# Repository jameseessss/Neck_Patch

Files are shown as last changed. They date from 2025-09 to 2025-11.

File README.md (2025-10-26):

# Neck Posture Rehab Patch
A lightweight, discreet neck-posture coach built on **nRF5340 + IMU**, providing real-time pitch/dwell estimation with **LRA haptics** and an optional **Peltier thermal cue**. The device connects over **BLE** for status streaming and parameter tuning.

> **What**: A wearable that senses head-neck posture and gently nudges you back to neutral.  
> **Why**: Prolonged forward-head posture is common with laptops/phones; this patch offers an adaptive, comfortable alternative to rigid braces.

---

## 📷 Bench & Design Gallery

<p align="center">
  Bench test of driver/LRA & Peltier control
</p>
<p align="center"><em>Figure 1 — Driver bench test (H-bridge + PWM + thermistor ADC). Used for LRA and Peltier bring-up.</em></p>

<p align="center">
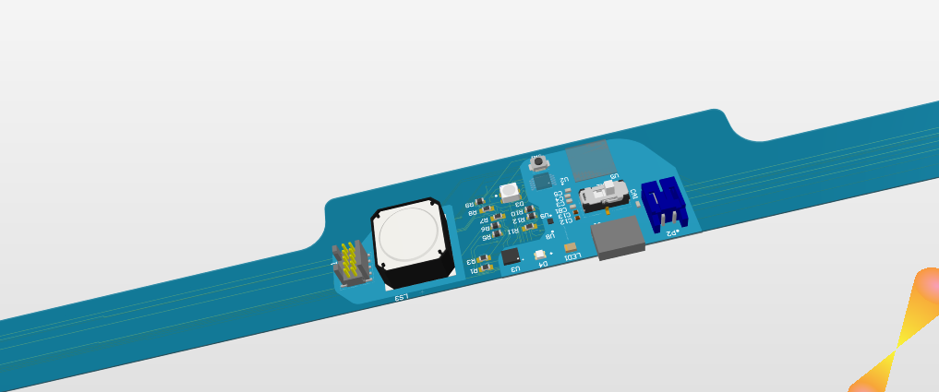
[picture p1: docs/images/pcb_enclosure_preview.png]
Preliminary flex PCB appearance / enclosure concept
  
</p>
<p align="center"><em>Figure 2 — Preliminary appearance concept for the flex PCB / enclosure.</em></p>

<p align="center">
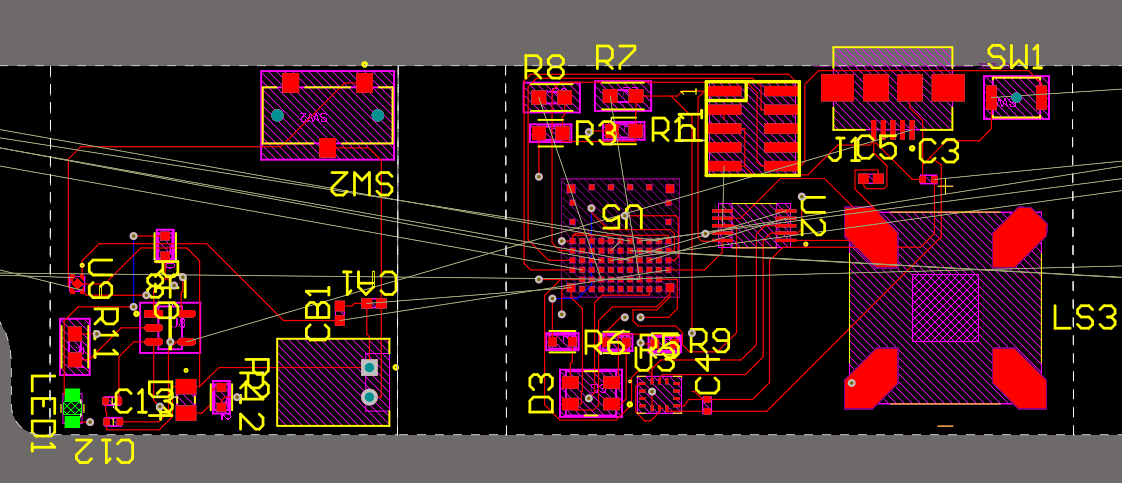
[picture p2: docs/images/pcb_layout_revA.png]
PCB Layout Rev-A (key nets and placement)
  
</p>
<p align="center"><em>Figure 3 — PCB Layout Rev-A snapshot: IMU, H-bridge, thermistor front-end, battery path.</em></p>

---

## ✨ Key Features
- **Real-time posture estimation**: 6-DoF IMU with *Madgwick* fusion for head-pitch tracking and **dwell time** measurement.
- **Fewer false triggers**: **Dynamic baseline** (adapts to user’s neutral drift) + **hysteresis thresholds** to avoid chatter.
- **Multi-modal feedback**:
  - **LRA haptics** with multiple intensity levels.
  - **Peltier thermal cue**: subtle skin-level warmth as a secondary, less intrusive signal.
- **BLE connectivity**: Custom **GATT** service for state notifications and command/control.
- **Safety & reliability**: Temperature/current limits, watchdog, emergency stop, error logging; OTA-ready (optional).
- **Early result**: Initial pilot suggests improved correction adherence over one week (larger study planned).

---

## 🧩 System Overview
- **MCU/SoC**: Nordic **nRF5340** (Zephyr RTOS) *(ESP32-S3 prototype supported)*  
- **Sensors**: BMI270 or ISM330DHCX (6-DoF IMU)  
- **Actuators**: LRA + driver; **Peltier + NTC** thermistor (optional)  
- **Connectivity**: BLE  
- **Power**: Single-cell Li-ion with charge/protection circuitry

### Thermal Subsystem (Peltier)
- **Purpose**: Provide a *gentle, low-salience* cue (warmth) when poor posture persists beyond a dwell threshold.
- **Control**: PWM-driven H-bridge → Peltier; closed-loop temperature control via **NTC** (skin-surface proxy).  
- **Algorithms**: NTC linearization, **slew-rate limiting**, and anti-windup.  
- **Safety limits (typical)**:
  - Skin-surface temperature cap (e.g., **≤ 42 °C** configurable)
  - Current limit with fold-back
  - Auto cool-down on over-temp / fault
- **Current HW rev**: Heating-focused; active cooling direction is possible with the H-bridge but disabled by default.

> ⚠️ **Note**: Thermal feedback targets *noticeable but comfortable* warmth. Actual limits should be validated per regulatory and dermatological guidance for wearables.

---

## 🔎 Current Status
- ✅ IMU fusion, posture logic, multi-level vibration  
- ✅ Peltier closed-loop heating with temp cap & current limit (pilot)

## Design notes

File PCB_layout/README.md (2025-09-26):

# ECE8873_Altium_sample

## Installing Altium
We have some specific instructions for installing, thanks to you classmate. Please see [these instructions](https://github.gatech.edu/ECE8873-Sensory-Sub-Aug/.github-private/blob/160f999e37ecde97cc4052183547c56a92e3dedc/profile/ALTIUM-Student%20License%20Request.pdf).

## Downloading sample
This is a git repository that you can clone like any other. It does not use the Altium workspace VCS. 
1. Fork this repository into the class organization
1. Use git command line tools to clone your fork on your desktop
1. In Altium, open the project (if it tells you the local copy is popinting to a VCS repository that is different from the one defined in the repository folder, PRESS CANCEL. Do not choose to get the repository from the ECE8873_sample or make the project local)
1. You can use the "Save to server" function in the project navigator to commit and push to your repository

## Working with Altium
- The main thing to start with in Altium is the schematic file and the board file (access these in the project navigation sidebar on left). In your project, you will most likely be adding additional sensors to your schematic, and then routing the board.
- Check for errors in the schematic (red zigzag lines)
- When you make changes to the schematic, go to the board file and click Design > Import changes from ...
- In the board file, you will see the footprints for the components arranged randomly. You will need to place them (move and rotate).
- There will be thin yellow lines telling you where connections need to be made. You need to route wires between each of these points (Ctrl + w). 
- The red traces are the top traces on the board, and the blue is the bottom traces. You can tunnel through the board with vias. While routing in interactive mode (Ctrl + w), switching between layers (Ctrl + Shift + scoll wheel) will automatically create a via.
- This sample contains good [design rules for PCBway](https://www.pcbway.com/capabilities.html). This is similar to the Altium .RUL file that they give [here](https://www.pcbway.com/helpcenter/design_instruction/PCBWay_Custom_Design_Rules.html), but I made some modifications.
- Check that your design passes clicking tools > Design rule check.

## Exporting for manufacturing by PCBway
- You will need to export both the gerber files and the drill files. See the guide [here](https://www.pcbway.com/blog/help_center/How_to_Generate_Gerber_and_Drill_Files_in_Altium_Designer_23_5_1_c436e1cc.html).
- The project includes samples of both the gerber and drill files.
- Make sure you look through each of the layers generated. Make sure your drills and soldermask layers show up in the right place.

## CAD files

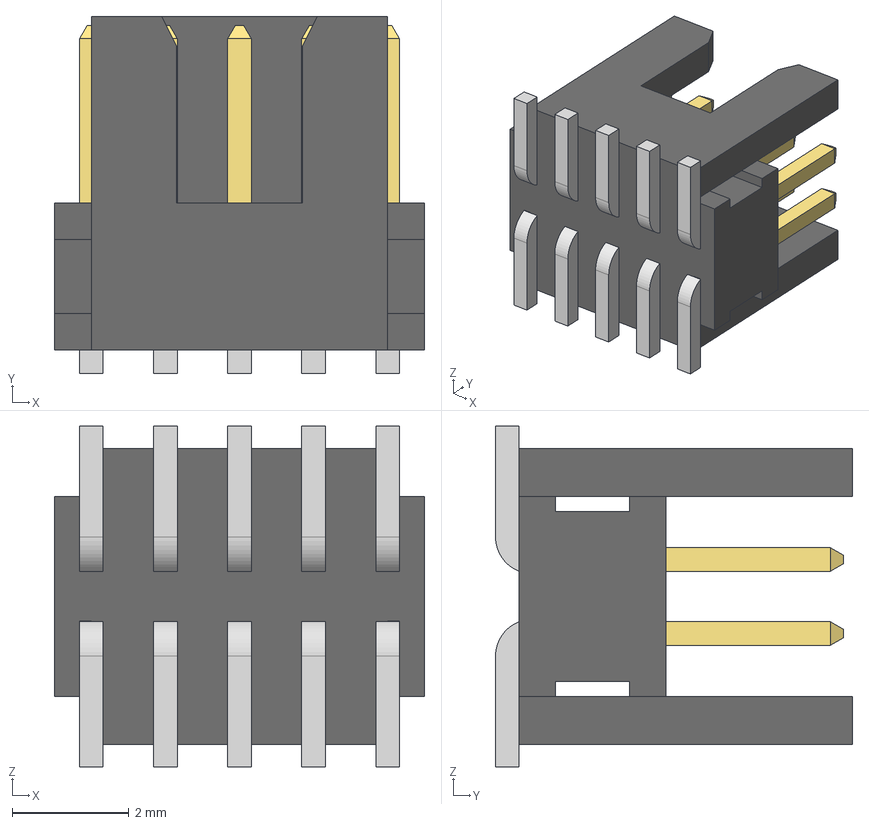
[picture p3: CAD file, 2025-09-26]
PCB_layout/Cad Files/FTSH-105-01-LM-DV-K-TR.stp
6.35 x 6.12 x 5.84 mm
FTSH-105-01-LM-DV-K-TR_body
FTSH-105-01-LM-DV-K-TR_pins1
FTSH-105-01-LM-DV-K-TR_pins2

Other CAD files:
PCB_layout/Cad Files/Temp Board Shape.SLDPRT
PCB_layout/Cad Files/RealFlex.SLDPRT
PCB_layout/Cad Files/RealFlex.DXF
PCB_layout/Cad Files/Temp Board Shape.DXF

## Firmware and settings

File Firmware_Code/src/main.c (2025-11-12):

/*
 * Copyright (c) 2021 Bosch Sensortec GmbH
 *
 * SPDX-License-Identifier: Apache-2.0
 */

#include <zephyr/kernel.h>
#include <zephyr/device.h>
#include <zephyr/devicetree.h>
#include <zephyr/drivers/sensor.h>
#include <zephyr/drivers/gpio.h>
#include <zephyr/drivers/adc.h>
#include <zephyr/drivers/pwm.h>
#include <zephyr/logging/log.h>
#include <math.h>
#include <stdio.h>
#include <stdint.h>
#include <errno.h>

LOG_MODULE_REGISTER(imu_test, LOG_LEVEL_INF);

/* ===== Thermistor Configuration ===== */
#define VREF_MV       3000.0
#define R_FIXED_OHM   10000.0
#define R0_OHM        10000.0
#define BETA          3950.0
#define T0_K          298.15
#define TEMP_CUTOFF   45.0

/* ===== PWM Peltier Configuration ===== */
#define PWM_PERIOD_NS   PWM_MSEC(10)   /* 10ms period */
#define PELTIER_OFF_NS  0
#define PELTIER_ON_NS   5000000        /* 50% duty cycle */

/* ===== LRA Vibration Motor Configuration ===== */
#define LRA_OFF_NS      0
#define LRA_ON_NS       5000000        /* 50% duty cycle */

/* ===== Global Variables ===== */
static int16_t adc_buf;
static struct adc_sequence adc_seq = {
    .buffer = &adc_buf,
    .buffer_size = sizeof(adc_buf),
};
static const struct adc_dt_spec adc_channel = ADC_DT_SPEC_GET(DT_PATH(zephyr_user));

/* ===== Function Declarations ===== */
static int read_thermistor_mv(int *out_mv);
static double thermistor_temp_c_from_mv(int vout_mv);
static int set_peltier_pwm(uint32_t pulse_ns);
static int set_lra_pwm(uint32_t pulse_ns);

/* ===== Thermistor Reading Function ===== */
static int read_thermistor_mv(int *out_mv)
{
    int err = adc_read(adc_channel.dev, &adc_seq);
    if (err < 0) {
        LOG_ERR("adc_read failed (%d)", err);
        return err;
    }
    int mv = (int)adc_buf;
    err = adc_raw_to_millivolts_dt(&adc_channel, &mv);
    if (err < 0) {
        LOG_WRN("adc_raw_to_millivolts not supported; raw=%d", (int)adc_buf);
        return -ENOTSUP;
    }
    *out_mv = mv;
    return 0;
}

/* ===== Temperature Calculation Function ===== */
static double thermistor_temp_c_from_mv(int vout_mv)
{
    if (vout_mv <= 1) vout_mv = 1;
    if (vout_mv >= (int)VREF_MV - 1) vout_mv = (int)VREF_MV - 1;

    double v = (double)vout_mv;
    double r_therm = R_FIXED_OHM * v / (VREF_MV - v); 
    double inv_T = (1.0 / T0_K) + (1.0 / BETA) * log(r_therm / R0_OHM);
    double T_k = 1.0 / inv_T;
    return T_k - 273.15;
}

/* ===== PWM Control Function ===== */
static int set_peltier_pwm(uint32_t pulse_ns)
{
    /* First Peltier: Use pwm_led0 alias */
    const struct pwm_dt_spec pwm_peltier1 = PWM_DT_SPEC_GET(DT_ALIAS(pwm_led0));
    /* Second Peltier: Use pwm_led2 alias (P1.12) */
    const struct pwm_dt_spec pwm_peltier2 = PWM_DT_SPEC_GET(DT_ALIAS(pwm_led2));
    
    int err1 = pwm_set_dt(&pwm_peltier1, PWM_PERIOD_NS, pulse_ns);
    int err2 = pwm_set_dt(&pwm_peltier2, PWM_PERIOD_NS, pulse_ns);
    
    if (err1 < 0) {
        LOG_ERR("Peltier1 PWM set failed (%d)", err1);
        return err1;
    }
    if (err2 < 0) {
        LOG_ERR("Peltier2 PWM set failed (%d)", err2);
        return err2;
    }
    
    return 0;
}

/* ===== LRA Vibration Motor Control Function ===== */
static int set_lra_pwm(uint32_t pulse_ns)
{
    const struct pwm_dt_spec pwm_lra1 = PWM_DT_SPEC_GET(DT_NODELABEL(lra_vib1));
    const struct pwm_dt_spec pwm_lra2 = PWM_DT_SPEC_GET(DT_NODELABEL(lra_vib2));
    
    int err1 = pwm_set_dt(&pwm_lra1, PWM_PERIOD_NS, pulse_ns);
    int err2 = pwm_set_dt(&pwm_lra2, PWM_PERIOD_NS, pulse_ns);
    
    if (err1 < 0) {
        LOG_ERR("LRA1 PWM set failed (%d)", err1);
        return err1;
    }
    if (err2 < 0) {
        LOG_ERR("LRA2 PWM set failed (%d)", err2);
        return err2;
    }
    
    return 0;
}

int main(void)
{
        const struct device *const dev = DEVICE_DT_GET_ONE(bosch_bmi270);
        struct sensor_value acc[3], gyr[3];
        struct sensor_value full_scale, sampling_freq, oversampling;
        
        /* LED GPIO device and pins */
        const struct device *gpio_dev = DEVICE_DT_GET(DT_NODELABEL(gpio0));
        
        /* Check if GPIO device is ready */
        if (!device_is_ready(gpio_dev)) {
                LOG_ERR("GPIO device not ready");
                return 0;
        }
        
        /* Configure LED pins as outputs */
        gpio_pin_configure(gpio_dev, 22, GPIO_OUTPUT_ACTIVE | GPIO_ACTIVE_HIGH);
        gpio_pin_configure(gpio_dev, 23, GPIO_OUTPUT_ACTIVE | GPIO_ACTIVE_HIGH);
        
        LOG_INF("LEDs configured on P0.22 and P0.23");
        
        /* Initialize ADC for thermistor (P0.04) */
        if (!adc_is_ready_dt(&adc_channel)) {
                LOG_ERR("ADC device not ready");
                return 0;
        }
        
        int ret = adc_channel_setup_dt(&adc_channel);
        if (ret < 0) {
                LOG_ERR("adc_channel_setup failed (%d)", ret);
                return 0;
        }
        
        ret = adc_sequence_init_dt(&adc_channel, &adc_seq);
        if (ret < 0) {
                LOG_ERR("adc_sequence_init failed (%d)", ret);
                return 0;
        }
        
        LOG_INF("ADC configured for thermistor on P0.04, channel %d", adc_channel.channel_id);
        LOG_INF("ADC device: %s, resolution: %d bits", adc_channel.dev->name, adc_channel.resolution);
        
        /* Test ADC reading */
        int test_mv = 0;
        ret = read_thermistor_mv(&test_mv);
        if (ret == 0) {
                LOG_INF("Initial ADC test: raw=%d, mV=%d", (int)adc_buf, test_mv);
        } else {
                LOG_ERR("Initial ADC test failed: %d", ret);
        }
        
        /* Initialize PWM for Peltiers */
        const struct pwm_dt_spec pwm_peltier1 = PWM_DT_SPEC_GET(DT_ALIAS(pwm_led0));
        const struct pwm_dt_spec pwm_peltier2 = PWM_DT_SPEC_GET(DT_ALIAS(pwm_led2));
        if (!pwm_is_ready_dt(&pwm_peltier1)) {
                LOG_ERR("Peltier1 PWM device not ready");
                return 0;
        }
        if (!pwm_is_ready_dt(&pwm_peltier2)) {
                LOG_ERR("Peltier2 PWM device not ready");
                return 0;
        }
        
        /* Disable Peltiers initially */
        set_peltier_pwm(PELTIER_OFF_NS);
        LOG_INF("PWM configured for Peltiers: P1.09 (Peltier1) and P1.12 (Peltier2)");
 
        if (!device_is_ready(dev)) {
                LOG_ERR("Device %s is not ready", dev->name);
                return 0;
        }

        LOG_INF("Device %p name is %s", dev, dev->name);
 
         /* Setting scale in G, due to loss of precision if the SI unit m/s^2
          * is used
          */
         full_scale.val1 = 2;            /* G */
         full_scale.val2 = 0;
         sampling_freq.val1 = 100;       /* Hz. Performance mode */
         sampling_freq.val2 = 0;
         oversampling.val1 = 1;          /* Normal mode */
         oversampling.val2 = 0;
 
        int rc;
        rc = sensor_attr_set(dev, SENSOR_CHAN_ACCEL_XYZ, SENSOR_ATTR_FULL_SCALE, &full_scale);
        if (rc) { LOG_ERR("Accel FULL_SCALE set failed (%d)", rc); }
        rc = sensor_attr_set(dev, SENSOR_CHAN_ACCEL_XYZ, SENSOR_ATTR_OVERSAMPLING, &oversampling);
        if (rc) { LOG_ERR("Accel OVERSAMPLING set failed (%d)", rc); }
         /* Set sampling frequency last as this also sets the appropriate
          * power mode. If already sampling, change to 0.0Hz before changing
          * other attributes
          */
        rc = sensor_attr_set(dev, SENSOR_CHAN_ACCEL_XYZ, SENSOR_ATTR_SAMPLING_FREQUENCY, &sampling_freq);
        if (rc) { LOG_ERR("Accel SAMPLING_FREQUENCY set failed (%d)", rc); }
 
 
         /* Setting scale in degrees/s to match the sensor scale */
         full_scale.val1 = 500;          /* dps */
         full_scale.val2 = 0;
         sampling_freq.val1 = 100;       /* Hz. Performance mode */
         sampling_freq.val2 = 0;
         oversampling.val1 = 1;          /* Normal mode */
         oversampling.val2 = 0;
 
        rc = sensor_attr_set(dev, SENSOR_CHAN_GYRO_XYZ, SENSOR_ATTR_FULL_SCALE, &full_scale);
        if (rc) { LOG_ERR("Gyro FULL_SCALE set failed (%d)", rc); }
        rc = sensor_attr_set(dev, SENSOR_CHAN_GYRO_XYZ, SENSOR_ATTR_OVERSAMPLING, &oversampling);
        if (rc) { LOG_ERR("Gyro OVERSAMPLING set failed (%d)", rc); }
         /* Set sampling frequency last as this also sets the appropriate
          * power mode. If already sampling, change sampling frequency to
          * 0.0Hz before changing other attributes
          */
        rc = sensor_attr_set(dev, SENSOR_CHAN_GYRO_XYZ, SENSOR_ATTR_SAMPLING_FREQUENCY, &sampling_freq);
        if (rc) { LOG_ERR("Gyro SAMPLING_FREQUENCY set failed (%d)", rc); }
 
        while (1) {
                /* 100ms period for better temperature monitoring */
                k_sleep(K_MSEC(100));

                rc = sensor_sample_fetch(dev);
                if (rc) {
                        LOG_ERR("sensor_sample_fetch failed (%d)", rc);
                        continue;
                }

                rc = sensor_channel_get(dev, SENSOR_CHAN_ACCEL_XYZ, acc);
                if (rc) { LOG_ERR("ACCEL_XYZ read failed (%d)", rc); }
                rc = sensor_channel_get(dev, SENSOR_CHAN_GYRO_XYZ, gyr);
                if (rc) { LOG_ERR("GYRO_XYZ read failed (%d)", rc); }

                /* Convert X acceleration to m/s^2 for comparison */
                double ax_ms2 = sensor_value_to_double(&acc[0]);
                
                /* Read temperature from thermistor */
                int mv = 0;
                double temp_c = NAN;
                ret = read_thermistor_mv(&mv);
                if (ret == 0) {
                        temp_c = thermistor_temp_c_from_mv(mv);
                }
                
                /* Control LEDs, Peltier, and LRA based on X acceleration and temperature */
                bool led_on = false;
                uint32_t peltier_ns = PELTIER_OFF_NS;
                uint32_t lra_ns = LRA_OFF_NS;
                
                if (ax_ms2 < 5.0) {
                        /* X acceleration < 5 m/s^2: turn on LEDs and LRA */
                        led_on = true;
                        gpio_pin_set(gpio_dev, 22, 1);
                        gpio_pin_set(gpio_dev, 23, 1);
                        lra_ns = LRA_ON_NS;  /* LRA vibration motor ON */
                        
                        /* Check temperature protection for Peltier */
                        if (!isnan(temp_c) && temp_c > TEMP_CUTOFF) {
                                peltier_ns = PELTIER_OFF_NS;
                                LOG_WRN("Temperature protection: %.1f°C >= %.1f°C -> Peltier OFF", 
                                        temp_c, TEMP_CUTOFF);
                        } else {
                                peltier_ns = PELTIER_ON_NS;
                                if (!isnan(temp_c)) {
                                        LOG_INF("Peltier ON (Temp=%.1f°C)", temp_c);
                                } else {
                                        LOG_INF("Peltier ON (Temp=N/A)");
                                }
                        }
                } else {
                        /* X acceleration >= 5 m/s^2: turn off LEDs, Peltier, and LRA */
                        led_on = false;
                        peltier_ns = PELTIER_OFF_NS;
                        lra_ns = LRA_OFF_NS;  /* LRA vibration motor OFF */
                        gpio_pin_set(gpio_dev, 22, 0);
                        gpio_pin_set(gpio_dev, 23, 0);
                }
                
                /* Set Peltier PWM */
                set_peltier_pwm(peltier_ns);
                
                /* Set LRA PWM */
                set_lra_pwm(lra_ns);

                /* printf output like reference code */
                printf("AX: %d.%06d AY: %d.%06d AZ: %d.%06d  "
                       "GX: %d.%06d GY: %d.%06d GZ: %d.%06d  ",
                       acc[0].val1, acc[0].val2, acc[1].val1, acc[1].val2, acc[2].val1, acc[2].val2,
                       gyr[0].val1, gyr[0].val2, gyr[1].val1, gyr[1].val2, gyr[2].val1, gyr[2].val2);

                if (ret == 0)      printf("[Therm=%dmV, %.1fC] ", mv, temp_c);
                printf("[LED=%s, Peltier=%s, LRA=%s]\n",
                       led_on ? "ON" : "OFF",
                       (peltier_ns == PELTIER_OFF_NS) ? "OFF" : "ON(50%)",
                       (lra_ns == LRA_OFF_NS) ? "OFF" : "ON(50%)");
        }
         return 0;
 }

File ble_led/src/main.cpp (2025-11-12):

#include <Arduino.h>
#include <WiFi.h>
#include <WebServer.h>
#include <Preferences.h>
#include <NimBLEDevice.h>

/************** Wi-Fi AP **************/
static const char* AP_SSID = "ESP32_Config";
static const char* AP_PASS = ""; // 空串=开放AP，如需加密，填8+位

/************** NVS 键 **************/
Preferences prefs;
static const char* NS = "cfg";
static const char* KEY_BLE_NAME = "bleName";
static const char* KEY_SVC_UUID  = "svcUUID";
static const char* KEY_CHR_UUID  = "chrUUID";

/************** 缺省配置 **************/
String g_targetName   = "nRF5340DK"; // 目标外设广播名
String g_serviceUUID  = "0000ffff-0000-1000-8000-00805f9b34fb";
String g_charUUID     = "0000ff01-0000-1000-8000-00805f9b34fb"; // 不确定可先保留，后用 /discover 查

/************** Web Server **************/
WebServer server(80);

/************** BLE 全局 **************/
NimBLEClient* g_client = nullptr;
NimBLERemoteCharacteristic* g_remoteChr = nullptr;
bool g_isConnecting = false;
unsigned long g_lastScanAttemptMs = 0;
const unsigned long RECONNECT_INTERVAL_MS = 5000;

/************** 页面 **************/
const char* HTML_PAGE = R"HTML(
<!doctype html><html><head>
<meta charset="utf-8"/><meta name="viewport" content="width=device-width,initial-scale=1"/>
<title>ESP32 BLE Config</title>
<style>
body{font-family:system-ui,-apple-system,Segoe UI,Roboto,Arial,sans-serif;margin:24px;max-width:720px}
h1{font-size:20px}label{display:block;margin:12px 0 6px}
input{width:100%;padding:10px;font-size:16px;box-sizing:border-box}
button{padding:10px 14px;font-size:16px;margin:6px 6px 6px 0;cursor:pointer}
.card{padding:16px;border:1px solid #ddd;border-radius:12px;margin-bottom:16px}
.row{display:flex;gap:8px;flex-wrap:wrap}.ok{color:#0a0}.bad{color:#a00}
code{background:#f5f5f5;padding:2px 6px;border-radius:6px}
</style></head><body>
<h1>ESP32 Web Config → BLE Control</h1>
<div class="card">
  <form method="POST" action="/save">
    <label>Target BLE Name (nRF5340DK advertising name)</label>
    <input name="bleName" value="%BLE_NAME%" required/>
    <label>Service UUID</label>
    <input name="svcUUID" value="%SVC_UUID%" required/>
    <label>Characteristic UUID (writable)</label>
    <input name="chrUUID" value="%CHR_UUID%" required/>
    <button type="submit">Save & Try Connect</button>
  </form>
</div>
<div class="card">
  <h3>Status</h3>
  <div id="status">Loading...</div>
  <div class="row">
    <button onclick="send('/led?state=on')">LED ON</button>
    <button onclick="send('/led?state=off')">LED OFF</button>
    <button onclick="send('/led?state=toggle')">TOGGLE</button>
    <button onclick="refresh()">Refresh</button>
    <button onclick="discover()">Discover</button>
  </div>
  <small>ESP32 writes: '1' / '0' / 'T'.</small>
</div>
<script>
function refresh(){
  fetch('/status').then(r=>r.json()).then(j=>{
    const ok=j.connected?'ok':'bad';
    document.getElementById('status').innerHTML=
      `<div>BLE Connected: <b class="${ok}">${j.connected}</b></div>
       <div>Target: <code>${j.bleName}</code></div>
       <div>Service: <code>${j.svcUUID}</code></div>
       <div>Char: <code>${j.chrUUID}</code></div>
       <div>Message: ${j.msg||''}</div>`;
  }).catch(_=>{document.getElementById('status').innerText='Failed to fetch status';});
}
function send(url){
  fetch(url,{method:'POST'}).then(r=>r.json()).then(j=>{
    alert(j.msg||JSON.stringify(j)); refresh();
  }).catch(_=>alert('Request failed'));
}
function discover(){
  fetch('/discover').then(r=>r.json()).then(j=>{
    alert((j.list&&j.list.length?j.list.join('\n'):'No services/chars found.'));
  }).catch(_=>alert('Discover failed'));
}
refresh();
</script>
</body></html>
)HTML";

/************** 小工具 **************/
String renderIndex() {
  String page = HTML_PAGE;
  page.replace("%BLE_NAME%", g_targetName);
  page.replace("%SVC_UUID%", g_serviceUUID);
  page.replace("%CHR_UUID%", g_charUUID);
  return page;
}

/************** 扫描 + 连接（注意 1.4.3 的返回类型） **************/
bool connectToTarget() {
  if (g_isConnecting) return false;
  g_isConnecting = true;

  if (g_client && g_client->isConnected()) { g_isConnecting = false; return true; }
  if (!g_client) {
    g_client = NimBLEDevice::createClient();
    g_client->setConnectTimeout(10);
  }

  NimBLEScan* scan = NimBLEDevice::getScan();
  scan->stop();
  scan->clearResults();
  scan->setActiveScan(true);
  scan->setInterval(45);
  scan->setWindow(30);
  scan->setDuplicateFilter(true);

  Serial.printf("[BLE] Scanning for: name='%s' or service=%s\n",
                g_targetName.c_str(), g_serviceUUID.c_str());

  // v1.4.3: start() 返回 NimBLEScanResults（不是 bool）
  NimBLEScanResults results = scan->start(7 /*seconds*/, false /*is_continue*/);
  Serial.printf("[DBG] 扫描完成, 发现 %d 个设备.\n", results.getCount());

  NimBLEUUID svcUUID(g_serviceUUID.c_str());
  bool found = false;
  NimBLEAddress candidateAddr;

  for (int i = 0; i < results.getCount(); ++i) {
    // v1.4.3: getDevice(i) 返回对象（不是指针），所以用 '.'
    NimBLEAdvertisedDevice d = results.getDevice(i);
    std::string nm = d.getName();

    Serial.printf("[DBG] Dev: %s RSSI=%d Name='%s'\n",
                  d.getAddress().toString().c_str(), d.getRSSI(), nm.c_str());

    bool nameHit = (!nm.empty() && String(nm.c_str()).equalsIgnoreCase(g_targetName));
    bool svcHit  = d.isAdvertisingService(svcUUID);

    if (nameHit || svcHit) {
      candidateAddr = d.getAddress();
      Serial.printf("[BLE] Candidate: %s (name='%s' svcHit=%c)\n",
                    candidateAddr.toString().c_str(), nm.c_str(), svcHit?'Y':'N');
      found = true;
      break;
    }
  }

  scan->clearResults();

  if (!found) {
    Serial.println("[BLE] Target not found.");
    g_isConnecting = false;
    return false;
  }

  Serial.printf("[BLE] Connecting to %s ...\n", candidateAddr.toString().c_str());
  if (!g_client->connect(candidateAddr)) {
    Serial.println("[BLE] Connect() failed.");
    g_isConnecting = false; return false;
  }
  Serial.println("[BLE] Connected.");

  // 找服务
  NimBLERemoteService* svc = g_client->getService(g_serviceUUID.c_str());
  if (!svc) {
    Serial.println("[BLE] Service NOT found on peer.");
    g_client->disconnect(); g_isConnecting = false; return false;
  }

  // 优先用配置的特征；找不到则自动挑一个“可写”的
  g_remoteChr = svc->getCharacteristic(g_charUUID.c_str());
  if (!g_remoteChr) {
    Serial.println("[BLE] Configured characteristic not found, try picking a writable one...");
    std::vector<NimBLERemoteCharacteristic*>* chs = svc->getCharacteristics(true);
    if (chs) {
      for (auto* c : *chs) {
        if (c->canWrite() || c->canWriteNoResponse()) { g_remoteChr = c; break; }
      }
    }
  }

  if (!g_remoteChr) {
    Serial.println("[BLE] No writable characteristic under the service.");
    g_client->disconnect(); g_isConnecting = false; return false;
  }

  if (!g_remoteChr->canWrite() && !g_remoteChr->canWriteNoResponse()) {
    Serial.println("[BLE] Selected characteristic is not writable.");
    g_client->disconnect(); g_isConnecting = false; return false;
  }
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

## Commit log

2025-10-26 Update main.c with PID
2025-10-26 Add bench & PCB images; update README gallery
2025-11-12 PCB testing
2025-11-12 Add configuration for pwm_led2 in app.overlay

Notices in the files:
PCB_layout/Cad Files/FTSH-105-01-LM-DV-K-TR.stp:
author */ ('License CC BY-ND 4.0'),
